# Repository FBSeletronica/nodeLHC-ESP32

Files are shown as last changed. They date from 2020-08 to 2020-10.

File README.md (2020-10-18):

## PT-BR

# nodeLHC-ESP32 



  



LIVE em formato Hands On Construindo o nova versão da placa de desenvolvimento nodeLHC ESP32, com o Pedro Minatel, utilizando a ferramenta Kicad, o módulo escolhido foi o ESP32 um microcontrolador de baixo custo da Espressif.

Em 2015 durante as oficinas de IoT no Hackerspace, criamos uma primeira versão do nodeLHC com o módulo ESP8266. Assim as pessoas aprenderam as diferentes etapas para construção de placa de circuitos impressos, também soldagem dos componentes da placa de desenvolvimento e programação para o módulo.

Descrições e detalhes:
Essa é uma primeira atividade que ao decorrer iremos construir novos projetos no formato aberto e colaborativo aproveitando a placa de desenvolvimento nodeLHC ESP32

- [KiCad](https://kicad-pcb.org/)
- [LHC KiCad Library](https://github.com/lhc/lhc_kicad_library)
- [Minatel KiCad Library](https://github.com/pedrominatel/minatel-kicad-libraries)
- [SparkFun KiCad Library](https://github.com/sparkfun/SparkFun-KiCad-Libraries)

# checklist
- [x] LIVE 1 - Explicação geral e desenho
- [x] LIVE 2 - Revisão esquemático e desenho da PCB parcial

# Próximos passos
- [ ] Lista de pessoas interessadas nos módulos
- [ ] Feedback comunidade
- [ ] LIVE 3 - Finalizar desenho da placa 
- [ ] Validar artes PCB
- [ ] Lista BOM
- [ ] Produção PCB

# Discourse 
Dúvidas? sugestões publicar na issues ou direto no discourse do LHC 

- [28/07/2020 LIVE - Hands On: Construindo o nodeLHC ESP32 com Kicad](https://discourse.lhc.net.br/t/28-07-2020-live-hands-on-construindo-o-nodelhc-esp32-com-kicad/148/2)
- [11/09/2020 LIVE - Hands On: Construindo o nodeLHC ESP32 com Kicad - Parte 02](https://discourse.lhc.net.br/t/11-09-2020-live-hands-on-construindo-o-nodelhc-esp32-com-kicad-parte-02/160)

# Ainda em construção 11/09/2020
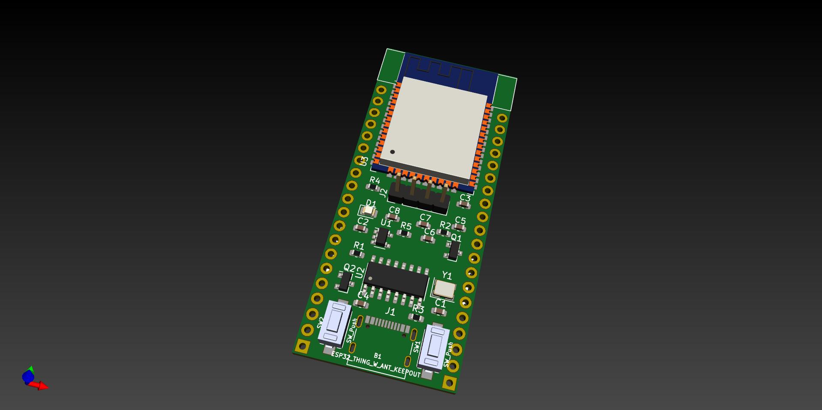
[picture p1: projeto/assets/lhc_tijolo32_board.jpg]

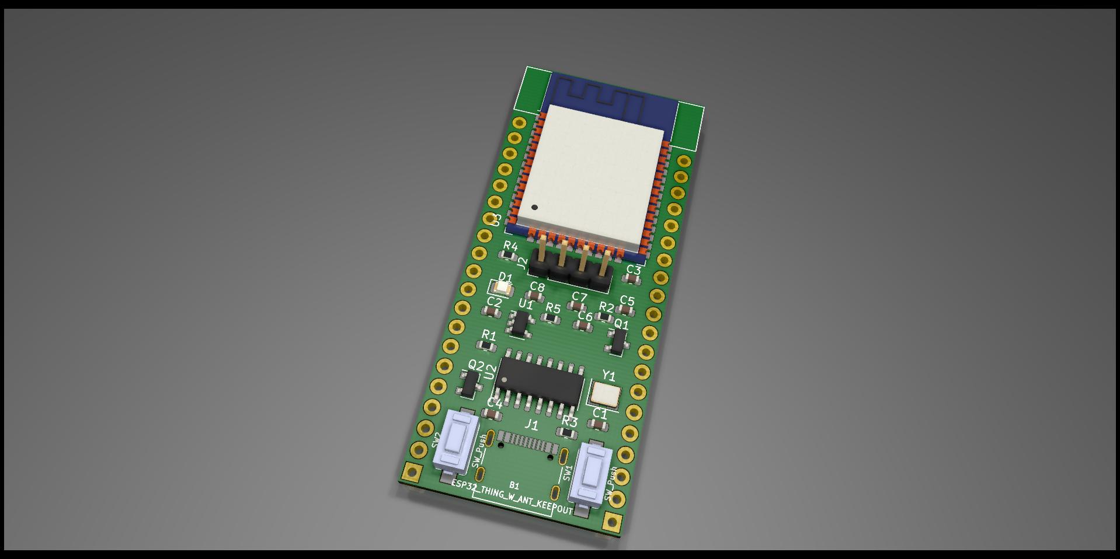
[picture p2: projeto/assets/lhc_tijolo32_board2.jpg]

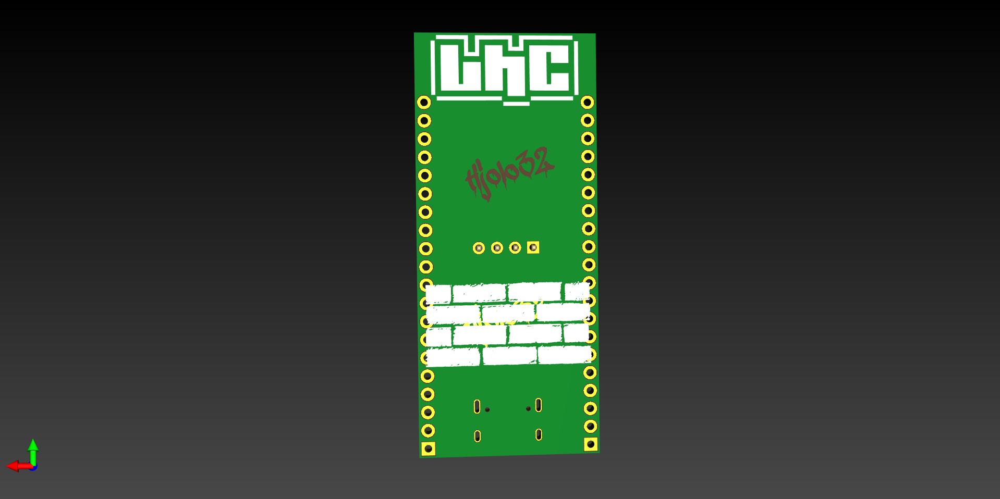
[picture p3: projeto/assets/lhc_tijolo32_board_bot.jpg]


# Log
- 19/08/2020 - Criado o evento, repositório, publicações nas redes sociais gerado link sobre a atividade.
- 02/09/2020 - Criado, divulgado o segundo evento, atualização de links no repositório.
- 06/10/2020 - Listagem das pessoas que responderam o discourse para receber o módulo ESP32

### Referencias

[ESP32 Datasheet](https://www.espressif.com/sites/default/files/documentation/esp32_datasheet_en.pdf)

[ESP32-WROOM Datasheet](https://www.espressif.com/sites/default/files/documentation/esp32-wroom-32d_esp32-wroom-32u_datasheet_en.pdf)

[ESP32 Design Guidelines](https://www.espressif.com/sites/default/files/documentation/esp32_hardware_design_guidelines_en.pdf)

[CH340G](https://cdn.sparkfun.com/datasheets/Dev/Arduino/Other/CH340DS1.PDF)

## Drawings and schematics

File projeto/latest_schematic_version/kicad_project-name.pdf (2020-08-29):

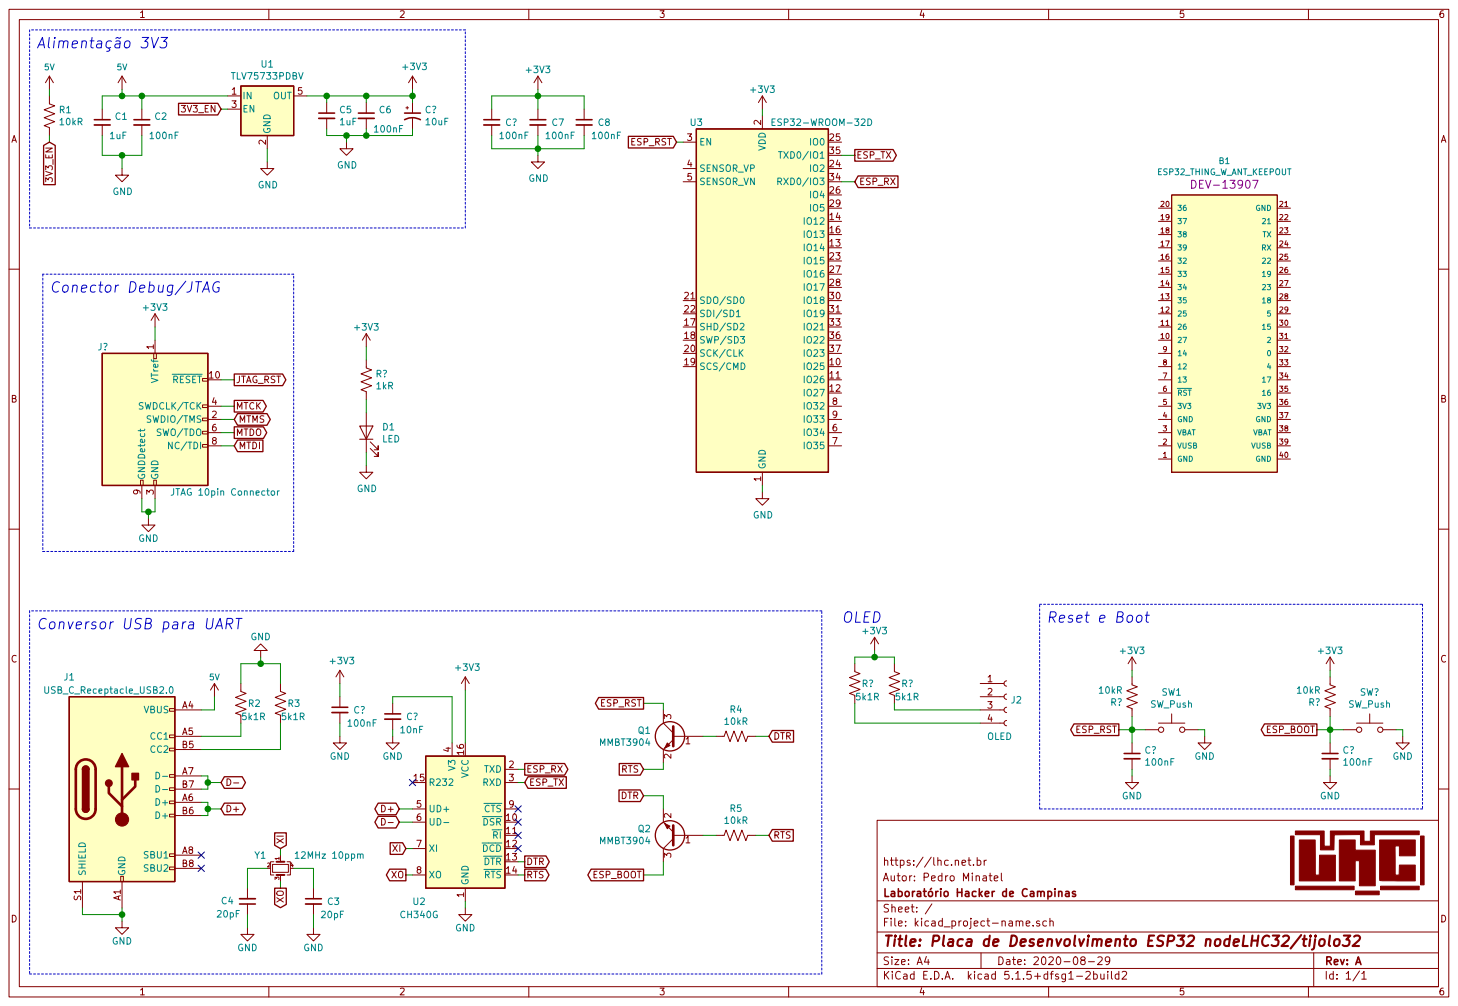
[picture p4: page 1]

2 SCK/CLK 20 SDO/SD0 21 SDI/SD1 22

3 SWDCLK/TCK 4 SWO/TDO 6 NC/TDI 8 GNDDetect 9

4 UD+ 5 UD- 6 XI 7 XO 8 CTS 9 U2 CH340G

1 DSR 10 RI 11 DCD 12 DTR 13 RTS 14 R232 15 VCC 16 TXD 2 RXD 3 V3

File: kicad_project-name.sch Sheet: / Laboratório Hacker de Campinas Autor: Pedro Minatel https://lhc.net.br

Id: 1/1 Title: Placa de Desenvolvimento ESP32 nodeLHC32/tijolo32

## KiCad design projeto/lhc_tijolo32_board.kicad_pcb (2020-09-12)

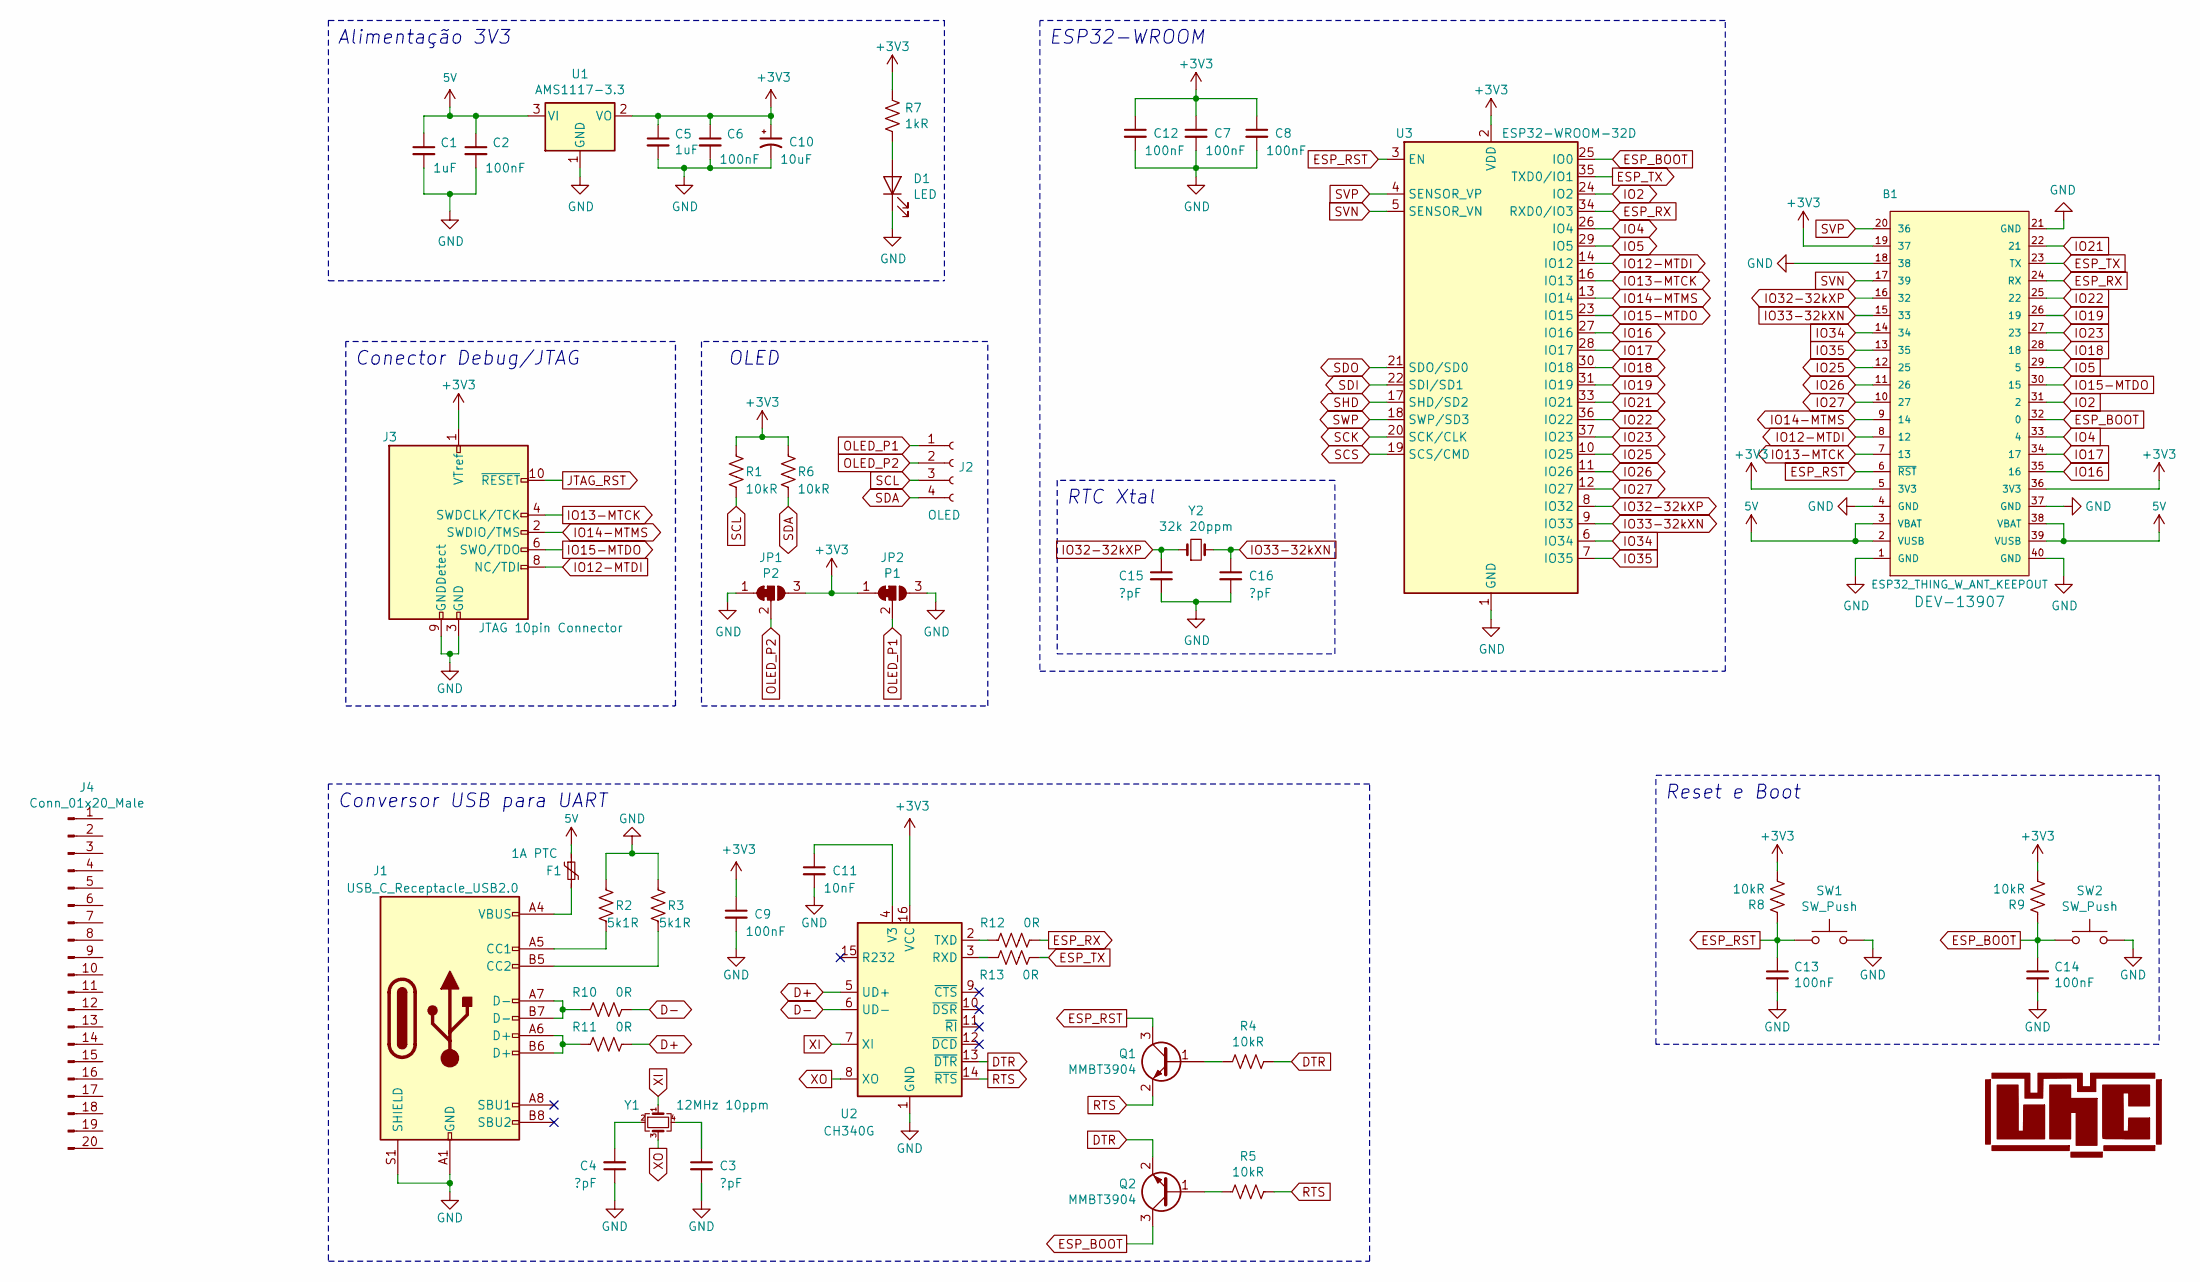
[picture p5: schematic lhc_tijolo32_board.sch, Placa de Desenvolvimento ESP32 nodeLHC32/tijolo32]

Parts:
B1: ESP32_THING_W_ANT_KEEPOUT; ESP32_THING
C1, C5: 1uF; C_0603_1608Metric
C2, C6, C7, C8, C9, C12, C13, C14: 100nF; C_0603_1608Metric
C3, C4, C15, C16: ?pF; C_0603_1608Metric
C10: 10uF; CP_EIA-3216-12_Kemet-S; LCSC C7171
C11: 10nF; C_0603_1608Metric
D1: LED; LED_0805_2012Metric
F1: 1A PTC; R_1210_3225Metric
J1: USB_C_Receptacle_USB2.0; USB_C_Receptacle_Palconn_UTC16-G
J2: OLED; PinHeader_1x04_P2.54mm_Vertical
J3: JTAG 10pin Connector; PinHeader_2x05_P1.27mm_Vertical_SMD
J4: Conn_01x20_Male; PinHeader_1x20_P2.54mm_Vertical
JP1: P2; SolderJumper-3_P1.3mm_Bridged12_Pad1.0x1.5mm_NumberLabels
JP2: P1; SolderJumper-3_P1.3mm_Bridged12_Pad1.0x1.5mm_NumberLabels
Q1, Q2: MMBT3904; SOT-23
R1, R4, R5, R6, R8, R9: 10kR; R_0603_1608Metric
R2, R3: 5k1R; R_0603_1608Metric
R7: 1kR; R_0603_1608Metric
R10, R11, R12, R13: 0R; R_0603_1608Metric
SW1, SW2: SW_Push; TACTILE_SWITCH_SMD_6.0X3.5MM
U1: AMS1117-3.3; SOT-223-3_TabPin2; LCSC C6186
U2: CH340G; SOIC-16_3.9x9.9mm_P1.27mm; MPN C14267
U3: ESP32-WROOM-32D; ESP32-WROOM-32
Y1: 12MHz 10ppm; Crystal_SMD_EuroQuartz_MT-4Pin_3.2x2.5mm
Y2: 32k 20ppm; Crystal_SMD_3215-2Pin_3.2x1.5mm

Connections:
5V: B1.2 (VUSB), B1.3 (VBAT), B1.38 (VBAT), B1.39 (VUSB), C1.1, C2.1, F1.1, U1.3 (VI)
+3V3: B1.5 (3V3), B1.19 (37), B1.36 (3V3), C5.1, C6.1, C7.1, C8.1, C9.1, C10.1, C12.1, J3.1 (VTref), JP1.3 (B), JP2.1 (A), R1.1, R6.1, R7.1, R8.2, R9.2, U1.2 (VO), U2.16 (VCC), U3.2 (VDD)
D+: R11.1, U2.5 (UD+)
D-: R10.1, U2.6 (UD-)
DTR: Q2.2 (E), R4.1, U2.13 (~DTR)
ESP_BOOT: B1.32 (0), C14.1, Q2.3 (C), R9.1, SW2.1, U3.25 (IO0)
ESP_RST: B1.6 (~RST~), C13.1, Q1.3 (C), R8.1, SW1.1, U3.3 (EN)
ESP_RX: B1.24 (RX), R12.1, U3.34 (RXD0/IO3)
ESP_TX: B1.23 (TX), R13.2, U3.35 (TXD0/IO1)
GND: B1.1 (GND), B1.4 (GND), B1.18 (38), B1.21 (GND), B1.37 (GND), B1.40 (GND), C1.2, C2.2, C3.2, C4.1, C5.2, C6.2, C7.2, C8.2, C9.2, C10.2, C11.2, C12.2, C13.2, C14.2, C15.2, C16.2, D1.1 (K), J1.A1 (GND), J1.A12 (GND), J1.B1 (GND), J1.B12 (GND), J1.S1 (SHIELD), J3.3 (GND), J3.5 (GND), J3.9 (GNDDetect), JP1.1 (A), JP2.3 (B), R2.1, R3.1, SW1.2, SW2.2, U1.1 (GND), U2.1 (GND), U3.1 (GND), U3.15 (GND), U3.38 (GND), U3.39 (GND)
IO2: B1.31 (2), U3.24 (IO2)
IO4: B1.33 (4), U3.26 (IO4)
IO5: B1.29 (5), U3.29 (IO5)
IO12-MTDI: B1.8 (12), J3.8 (NC/TDI), U3.14 (IO12)
IO13-MTCK: B1.7 (13), J3.4 (SWDCLK/TCK), U3.16 (IO13)
IO14-MTMS: B1.9 (14), J3.2 (SWDIO/TMS), U3.13 (IO14)
IO15-MTDO: B1.30 (15), J3.6 (SWO/TDO), U3.23 (IO15)
IO16: B1.35 (16), U3.27 (IO16)
IO17: B1.34 (17), U3.28 (IO17)
IO18: B1.28 (18), U3.30 (IO18)
IO19: B1.26 (19), U3.31 (IO19)
IO21: B1.22 (21), U3.33 (IO21)
IO22: B1.25 (22), U3.36 (IO22)
IO23: B1.27 (23), U3.37 (IO23)
IO25: B1.12 (25), U3.10 (IO25)
IO26: B1.11 (26), U3.11 (IO26)
IO27: B1.10 (27), U3.12 (IO27)
IO32-32kXP: B1.16 (32), C15.1, U3.8 (IO32), Y2.1
IO33-32kXN: B1.15 (33), C16.1, U3.9 (IO33), Y2.2
IO34: B1.14 (34), U3.6 (IO34)
IO35: B1.13 (35), U3.7 (IO35)
JTAG_RST: J3.10 (~RESET~)
unnamed: C3.1, Y1.4
unnamed: C4.2, Y1.2
unnamed: C11.1, U2.4 (V3)
unnamed: D1.2 (A), R7.2
unnamed: F1.2, J1.A4 (VBUS), J1.A9 (VBUS), J1.B4 (VBUS), J1.B9 (VBUS)
unnamed: J1.A5 (CC1), R2.2
unnamed: J1.A6 (D+), J1.B6 (D+), R11.2
unnamed: J1.A7 (D-), J1.B7 (D-), R10.2
unnamed: J1.B5 (CC2), R3.2
unnamed: Q1.1 (B), R4.2
unnamed: Q2.1 (B), R5.2
unnamed: R12.2, U2.2 (TXD)
unnamed: R13.1, U2.3 (RXD)
OLED_P1: J2.1, JP2.2 (C)
OLED_P2: J2.2, JP1.2 (C)
RTS: Q1.2 (E), R5.1, U2.14 (~RTS)
SCK: U3.20 (SCK/CLK)
SCL: J2.3, R1.2
SCS: U3.19 (SCS/CMD)
SDA: J2.4, R6.2
SDI: U3.22 (SDI/SD1)
SDO: U3.21 (SDO/SD0)
SHD: U3.17 (SHD/SD2)
SVN: B1.17 (39), U3.5 (SENSOR_VN)
SVP: B1.20 (36), U3.4 (SENSOR_VP)
SWP: U3.18 (SWP/SD3)
XI: U2.7 (XI), Y1.1
XO: U2.8 (XO), Y1.3

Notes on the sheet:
Alimentação 3V3
Conversor USB para UART
Conector Debug/JTAG
Reset e Boot
OLED
ESP32-WROOM
RTC Xtal

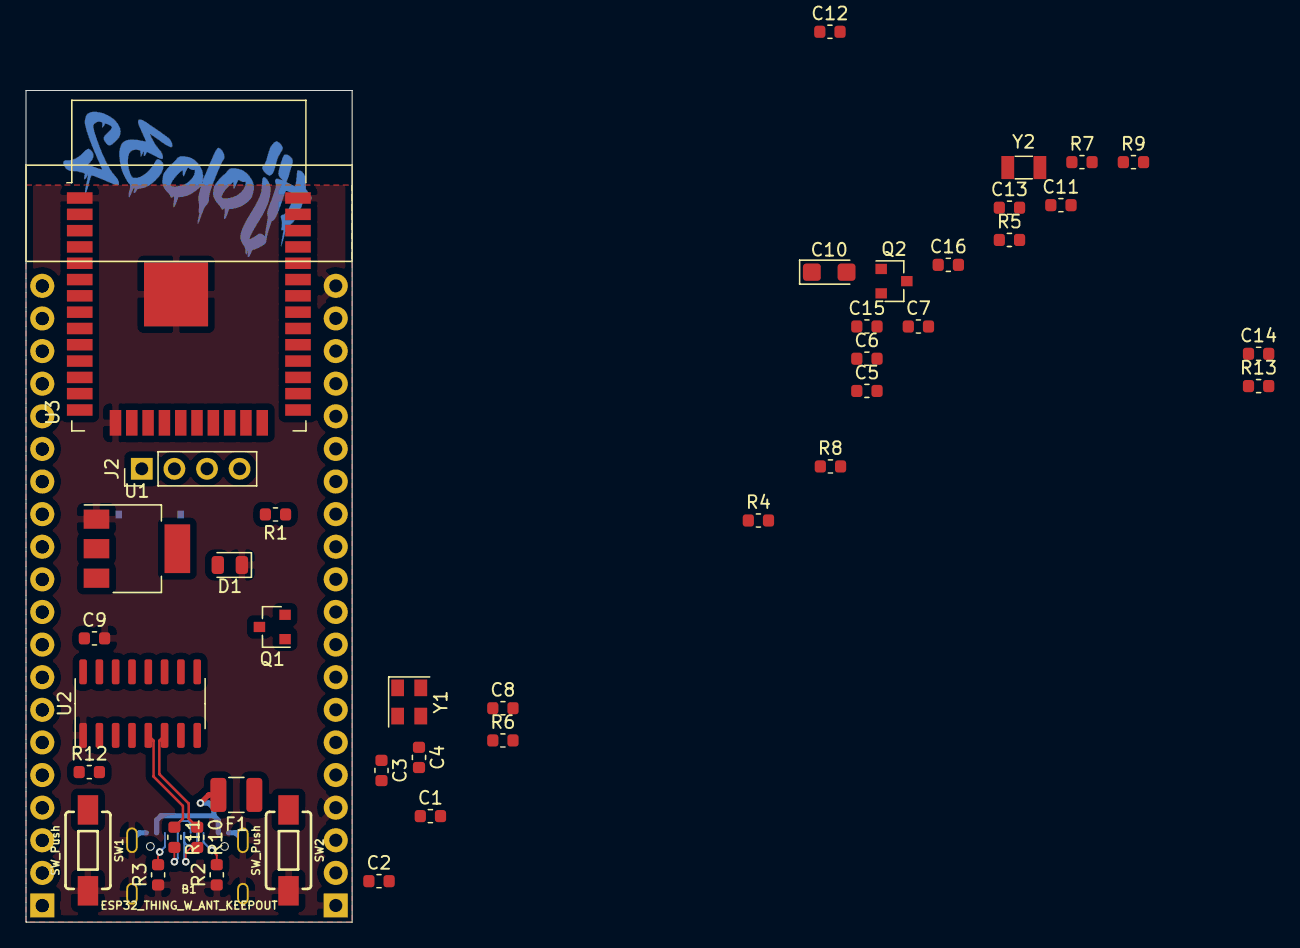
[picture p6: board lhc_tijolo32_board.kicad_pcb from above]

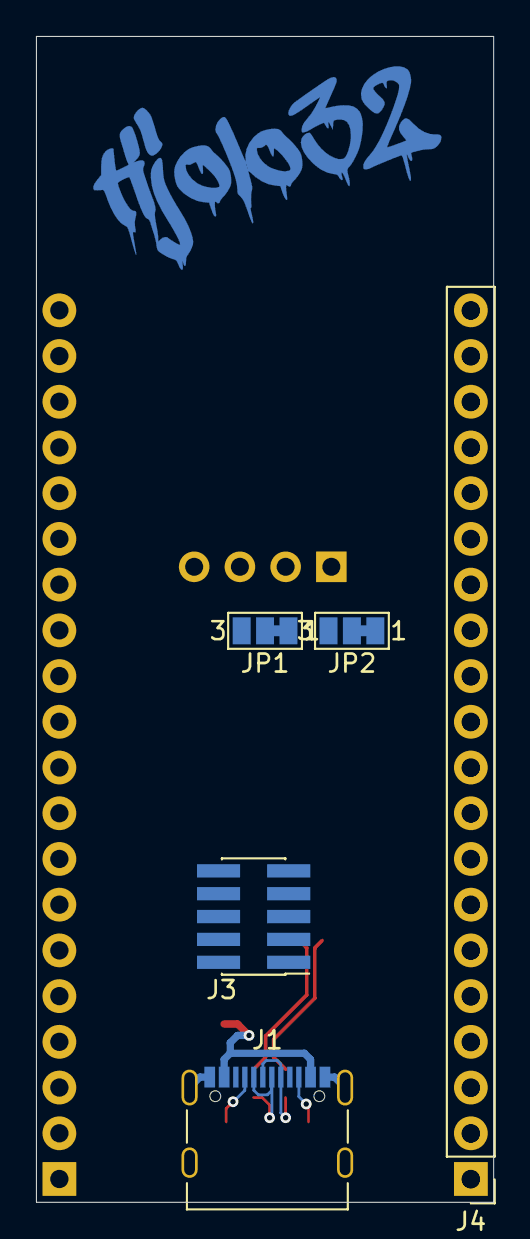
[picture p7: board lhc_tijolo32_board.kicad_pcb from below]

Board: 2 copper layers, 25.4 x 64.8 mm, 47 parts (5 on the bottom side), 53 nets.

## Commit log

2020-08-29 Arquivos da live adicionados
    [kicad_project-name.kicad_pcb, kicad_project-name.sch]
2020-08-29 Troca do LDO para AMS1117-3-3
    [kicad_project-name.sch]
2020-08-29 Botão de reset/boot e conector OLED
    [kicad_project-name.sch]
2020-09-11 Sch WIP.Sync for live.
    [lhc_tijolo32_board.kicad_pcb, lhc_tijolo32_board.sch]
2020-09-11 Schematic update
    [lhc_tijolo32_board-B_Cu.gbr, lhc_tijolo32_board-B_Mask.gbr, lhc_tijolo32_board-B_Paste.gbr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]
